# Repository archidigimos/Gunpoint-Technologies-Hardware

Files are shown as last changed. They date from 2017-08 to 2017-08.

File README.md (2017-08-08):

# Gunpoint-Technologies-Hardware
Lasertag gaming hardware. Product developed for gaming, entertainment and battlefield simulation purpose for military.
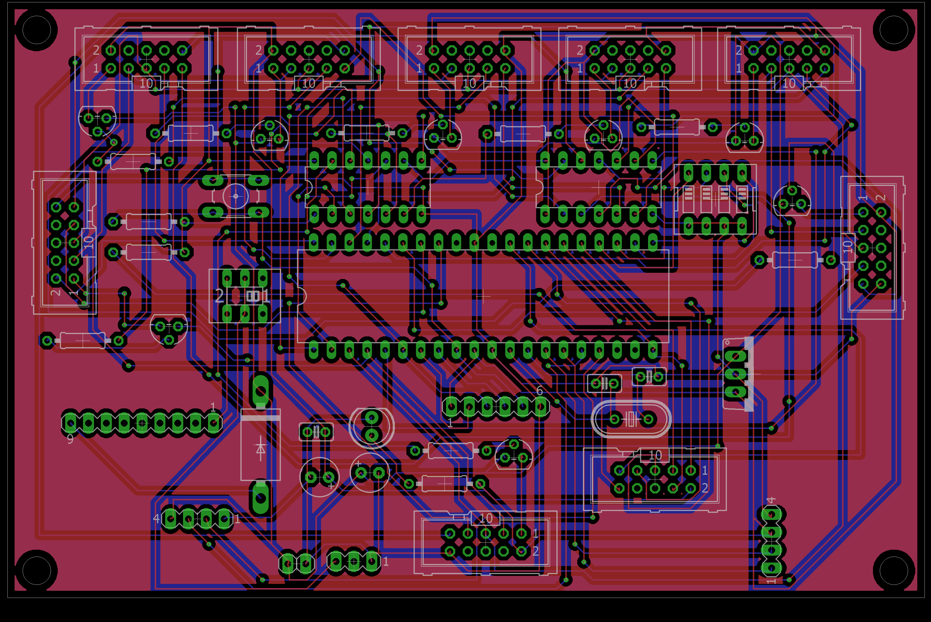
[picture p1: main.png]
Logic board to control sensor boards

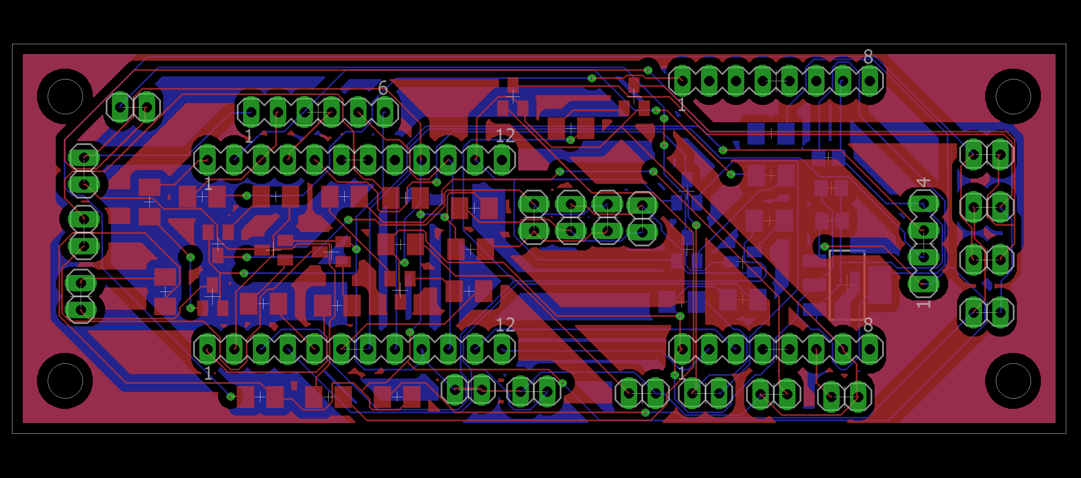
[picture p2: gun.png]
Gun logic board

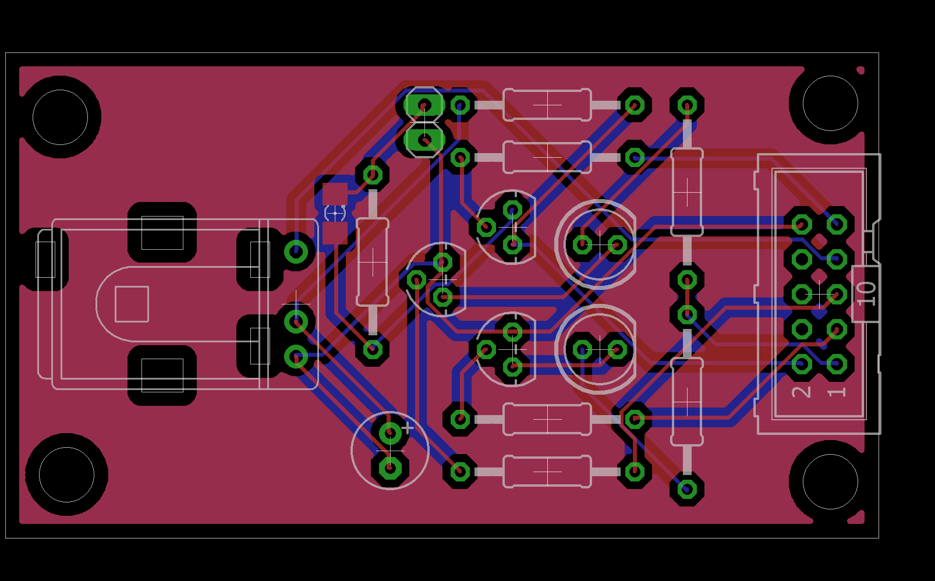
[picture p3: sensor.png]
Sensor board


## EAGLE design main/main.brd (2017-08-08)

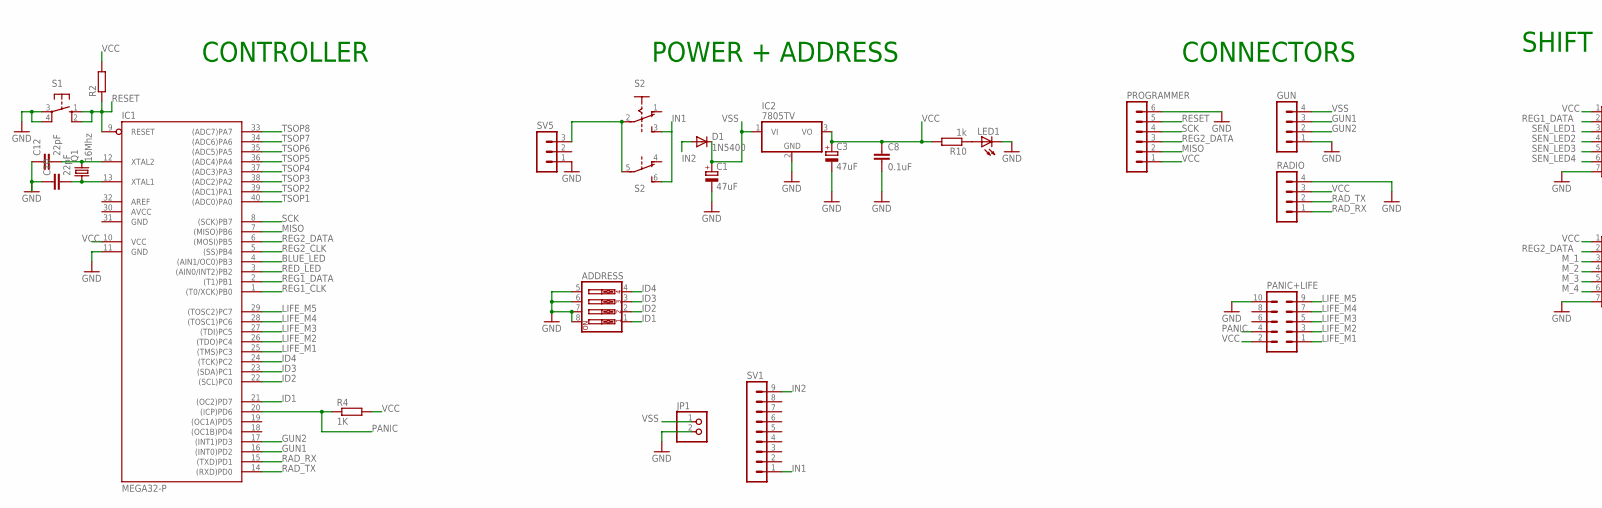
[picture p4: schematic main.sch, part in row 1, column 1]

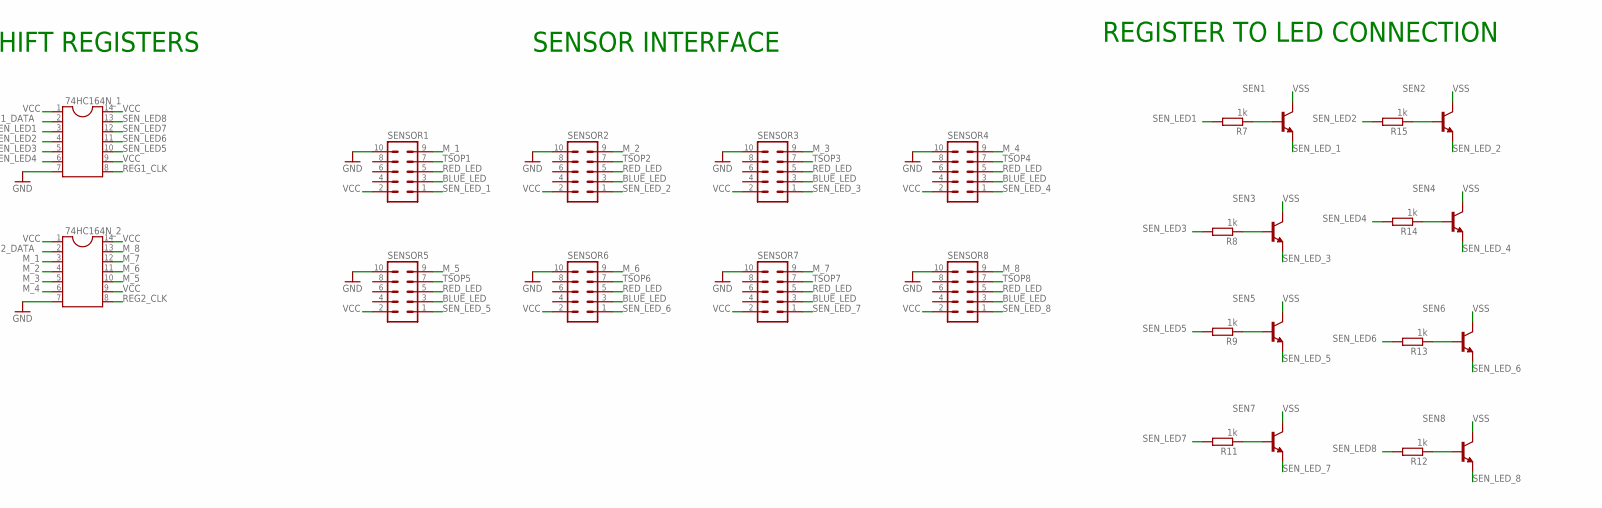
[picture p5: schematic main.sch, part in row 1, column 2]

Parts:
74HC164N_1, 74HC164N_2: DIL14
ADDRESS: SW_DIP-4; EDG-04
C1, C3: 47uF; E2,5-6
C8: 0.1uF; C025-025X050
C10, C12: 22pF; C025-025X050
D1: 1N5400; DO201-15
GUN: MA04-1
IC1: MEGA32-P; DIL40
IC2: 7805TV; TO220V
JP1: PINHD-1X2; 1X02
LED1: LED5MM
PANIC+LIFE: ML10
PROGRAMMER: MA06-1
Q1: 16Mhz; HC49U70
R2: R-EU_0207/10; 0207/10
R4: 1K; 0207/10
R7, R8, R9, R10, R11, R12, R13, R14, R15: 1k; 0207/10
RADIO: MA04-1
S1: 10-XX; B3F-10XX
S2: A68-A31
SEN1, SEN2, SEN3, SEN4, SEN5, SEN6, SEN7, SEN8: BC547; TO92
SENSOR1, SENSOR2, SENSOR3, SENSOR4, SENSOR5, SENSOR6, SENSOR7, SENSOR8: ML10
SV1: MA09-1
SV5: MA03-1

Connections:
AVCC: IC1.30 (AVCC)
BLUE_LED: IC1.4 ((AIN1/OC0)PB3), SENSOR1.3, SENSOR2.3, SENSOR3.3, SENSOR4.3, SENSOR5.3, SENSOR6.3, SENSOR7.3, SENSOR8.3
GND: 74HC164N_1.7, 74HC164N_2.7, ADDRESS.5, ADDRESS.6, ADDRESS.7, ADDRESS.8, C1.-, C3.-, C8.2, C10.1, C12.1, GUN.1, IC1.11 (GND), IC1.31 (GND), IC2.2 (GND), JP1.2, LED1.K (C), PANIC+LIFE.10, PROGRAMMER.6, RADIO.4, S1.3, S1.4 (P1), SENSOR1.10, SENSOR2.10, SENSOR3.10, SENSOR4.10, SENSOR5.10, SENSOR6.10, SENSOR7.10, SENSOR8.10, SV5.1
GUN1: GUN.3, IC1.16 ((INT0)PD2)
GUN2: GUN.2, IC1.17 ((INT1)PD3)
ID1: ADDRESS.1, IC1.21 ((OC2)PD7)
ID2: ADDRESS.2, IC1.22 ((SCL)PC0)
ID3: ADDRESS.3, IC1.23 ((SDA)PC1)
ID4: ADDRESS.4, IC1.24 ((TCK)PC2)
IN1: S2.3 (S), S2.6 (S), SV1.1
IN2: D1.A, SV1.9
LIFE_M1: IC1.25 ((TMS)PC3), PANIC+LIFE.1
LIFE_M2: IC1.26 ((TDO)PC4), PANIC+LIFE.3
LIFE_M3: IC1.27 ((TDI)PC5), PANIC+LIFE.5
LIFE_M4: IC1.28 ((TOSC1)PC6), PANIC+LIFE.7
LIFE_M5: IC1.29 ((TOSC2)PC7), PANIC+LIFE.9
MISO: IC1.7 ((MISO)PB6), PROGRAMMER.2
M_1: 74HC164N_2.3, SENSOR1.9
M_2: 74HC164N_2.4, SENSOR2.9
M_3: 74HC164N_2.5, SENSOR3.9
M_4: 74HC164N_2.6, SENSOR4.9
M_5: 74HC164N_2.10, SENSOR5.9
M_6: 74HC164N_2.11, SENSOR6.9
M_7: 74HC164N_2.12, SENSOR7.9
M_8: 74HC164N_2.13, SENSOR8.9
unnamed: C12.2, IC1.12 (XTAL2), Q1.2
unnamed: C10.2, IC1.13 (XTAL1), Q1.1
unnamed: LED1.A, R10.1
unnamed: R7.1, SEN1.2 (B)
unnamed: R15.1, SEN2.2 (B)
unnamed: S2.2, S2.5, SV5.3
unnamed: R8.1, SEN3.2 (B)
unnamed: R14.1, SEN4.2 (B)
unnamed: R9.1, SEN5.2 (B)
unnamed: R13.1, SEN6.2 (B)
unnamed: R11.1, SEN7.2 (B)
unnamed: R12.1, SEN8.2 (B)
PANIC: IC1.20 ((ICP)PD6), PANIC+LIFE.4, R4.1
RAD_RX: IC1.15 ((TXD)PD1), RADIO.1
RAD_TX: IC1.14 ((RXD)PD0), RADIO.2
RED_LED: IC1.3 ((AIN0/INT2)PB2), SENSOR1.5, SENSOR2.5, SENSOR3.5, SENSOR4.5, SENSOR5.5, SENSOR6.5, SENSOR7.5, SENSOR8.5
REG1_CLK: 74HC164N_1.8, IC1.1 ((T0/XCK)PB0)
REG1_DATA: 74HC164N_1.2, IC1.2 ((T1)PB1)
REG2_CLK: 74HC164N_2.8, IC1.5 ((SS)PB4)
REG2_DATA: 74HC164N_2.2, IC1.6 ((MOSI)PB5), PROGRAMMER.3
RESET: IC1.9 (RESET), PROGRAMMER.5, R2.1, S1.1 (S), S1.2 (S1)
SCK: IC1.8 ((SCK)PB7), PROGRAMMER.4
SEN_LED1: 74HC164N_1.3, R7.2
SEN_LED2: 74HC164N_1.4, R15.2
SEN_LED3: 74HC164N_1.5, R8.2
SEN_LED4: 74HC164N_1.6, R14.2
SEN_LED5: 74HC164N_1.10, R9.2
SEN_LED6: 74HC164N_1.11, R13.2
SEN_LED7: 74HC164N_1.12, R11.2
SEN_LED8: 74HC164N_1.13, R12.2
SEN_LED_1: SEN1.1 (E), SENSOR1.1
SEN_LED_2: SEN2.1 (E), SENSOR2.1
SEN_LED_3: SEN3.1 (E), SENSOR3.1
SEN_LED_4: SEN4.1 (E), SENSOR4.1
SEN_LED_5: SEN5.1 (E), SENSOR5.1
SEN_LED_6: SEN6.1 (E), SENSOR6.1
SEN_LED_7: SEN7.1 (E), SENSOR7.1
SEN_LED_8: SEN8.1 (E), SENSOR8.1
TSOP1: IC1.40 ((ADC0)PA0), SENSOR1.7
TSOP2: IC1.39 ((ADC1)PA1), SENSOR2.7
TSOP3: IC1.38 ((ADC2)PA2), SENSOR3.7
TSOP4: IC1.37 ((ADC3)PA3), SENSOR4.7
TSOP5: IC1.36 ((ADC4)PA4), SENSOR5.7
TSOP6: IC1.35 ((ADC5)PA5), SENSOR6.7
TSOP7: IC1.34 ((ADC6)PA6), SENSOR7.7
TSOP8: IC1.33 ((ADC7)PA7), SENSOR8.7
VCC: 74HC164N_1.1, 74HC164N_1.9, 74HC164N_1.14, 74HC164N_2.1, 74HC164N_2.9, 74HC164N_2.14, C3.+, C8.1, IC1.10 (VCC), IC2.3 (VO), PANIC+LIFE.2, PROGRAMMER.1, R2.2, R4.2, R10.2, RADIO.3, SENSOR1.2, SENSOR2.2, SENSOR3.2, SENSOR4.2, SENSOR5.2, SENSOR6.2, SENSOR7.2, SENSOR8.2
VSS: C1.+, D1.C, GUN.4, IC2.1 (VI), JP1.1, SEN1.3 (C), SEN2.3 (C), SEN3.3 (C), SEN4.3 (C), SEN5.3 (C), SEN6.3 (C), SEN7.3 (C), SEN8.3 (C)

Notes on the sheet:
CONTROLLER
POWER + ADDRESS
CONNECTORS
SHIFT REGISTERS
SENSOR INTERFACE
REGISTER TO LED CONNECTION

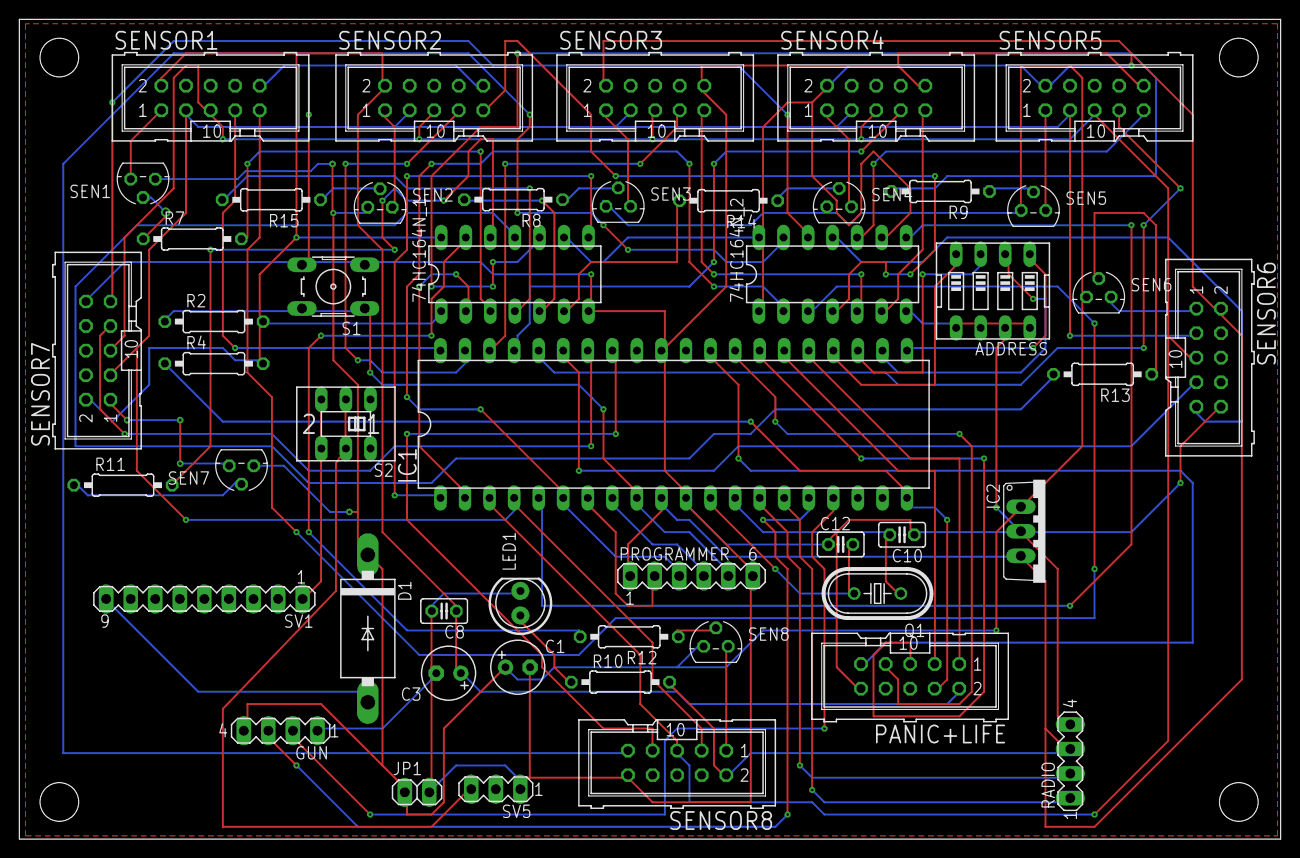
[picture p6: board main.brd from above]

Board: 2 copper layers, 130.5 x 84.8 mm, 49 parts (0 on the bottom side), 72 nets.

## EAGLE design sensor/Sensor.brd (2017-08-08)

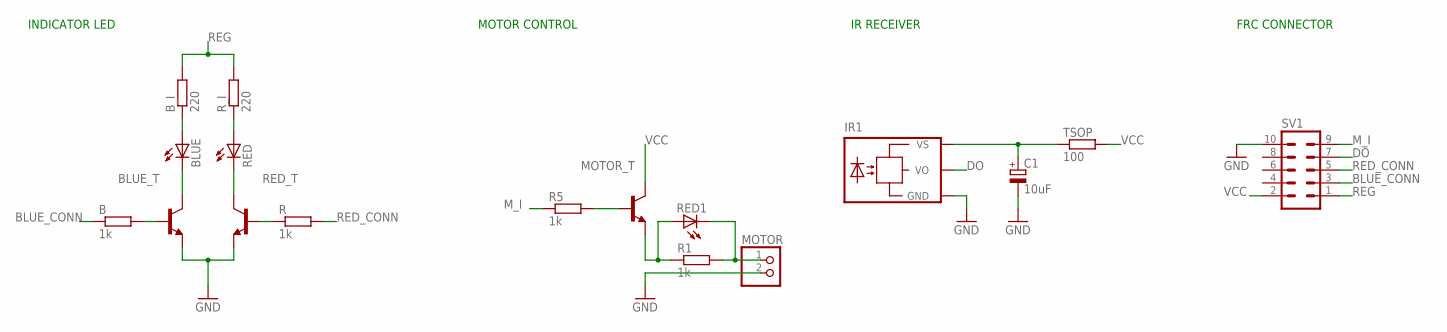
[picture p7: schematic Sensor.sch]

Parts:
B: 1k; 0207/12
BLUE: LED5MM
BLUE_T: BC547; TO92
B_I: 220; 0207/12
C1: 10uF; E2,5-6
IR1: TSOP1730TB1; TSOP17_TB1
MOTOR: PINHD-1X2; 1X02
MOTOR_T: BC547; TO92
R, R1, R5: 1k; 0207/12
RED: LED5MM
RED1: LEDSMT1206; 1206
RED_T: BC547; TO92
R_I: 220; 0207/12
SV1: ML10
TSOP: 100; 0207/12

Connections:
BLUE_CONN: B.1, SV1.3
DO: IR1.VO, SV1.7
GND: BLUE_T.1 (E), C1.-, IR1.GND, MOTOR.2, RED_T.1 (E), SV1.10
M_I: R5.1, SV1.9
unnamed: BLUE.A, B_I.1
unnamed: C1.+, IR1.VS, TSOP.1
unnamed: BLUE.K (C), BLUE_T.3 (C)
unnamed: RED.K (C), RED_T.3 (C)
unnamed: MOTOR_T.2 (B), R5.2
unnamed: MOTOR_T.1 (E), R1.1, RED1.A
unnamed: B.2, BLUE_T.2 (B)
unnamed: R.1, RED_T.2 (B)
unnamed: MOTOR.1, R1.2, RED1.C
RED_CONN: R.2, SV1.5
REG: B_I.2, R_I.2, SV1.1
R_I: RED.A, R_I.1
VCC: MOTOR_T.3 (C), SV1.2, TSOP.2

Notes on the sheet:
INDICATOR LED
MOTOR CONTROL
IR RECEIVER
FRC CONNECTOR

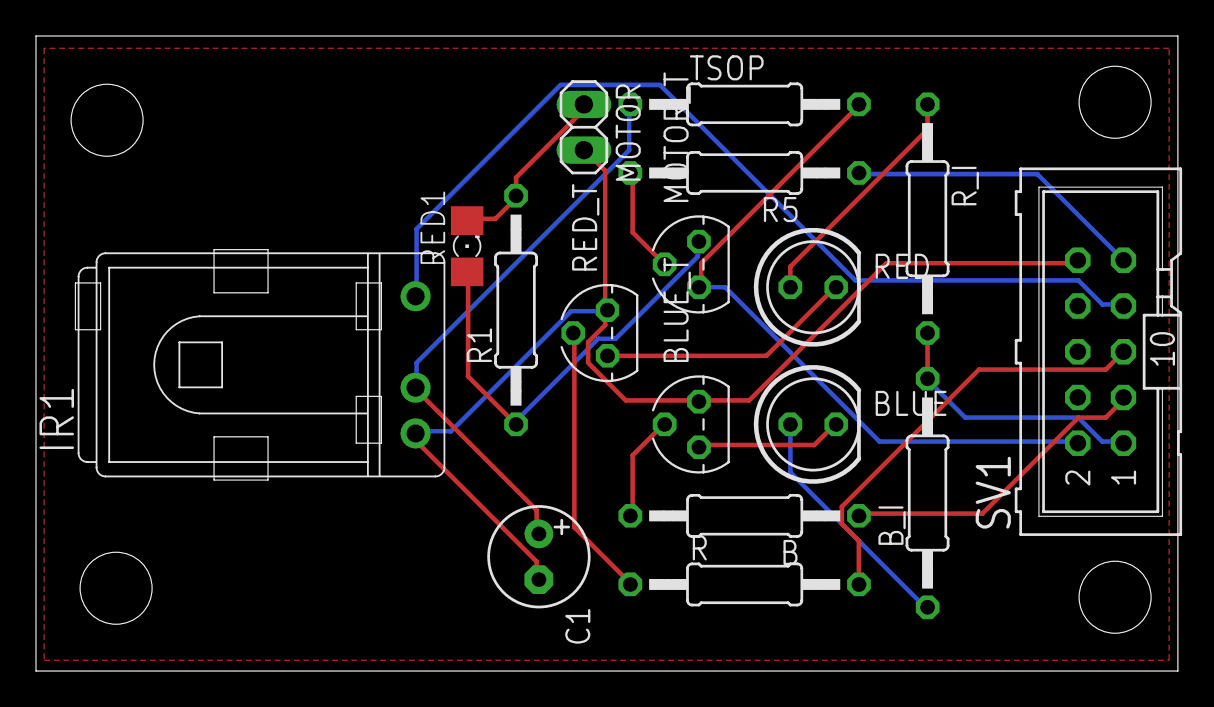
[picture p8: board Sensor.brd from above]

Board: 2 copper layers, 63.4 x 35.3 mm, 17 parts (0 on the bottom side), 17 nets.

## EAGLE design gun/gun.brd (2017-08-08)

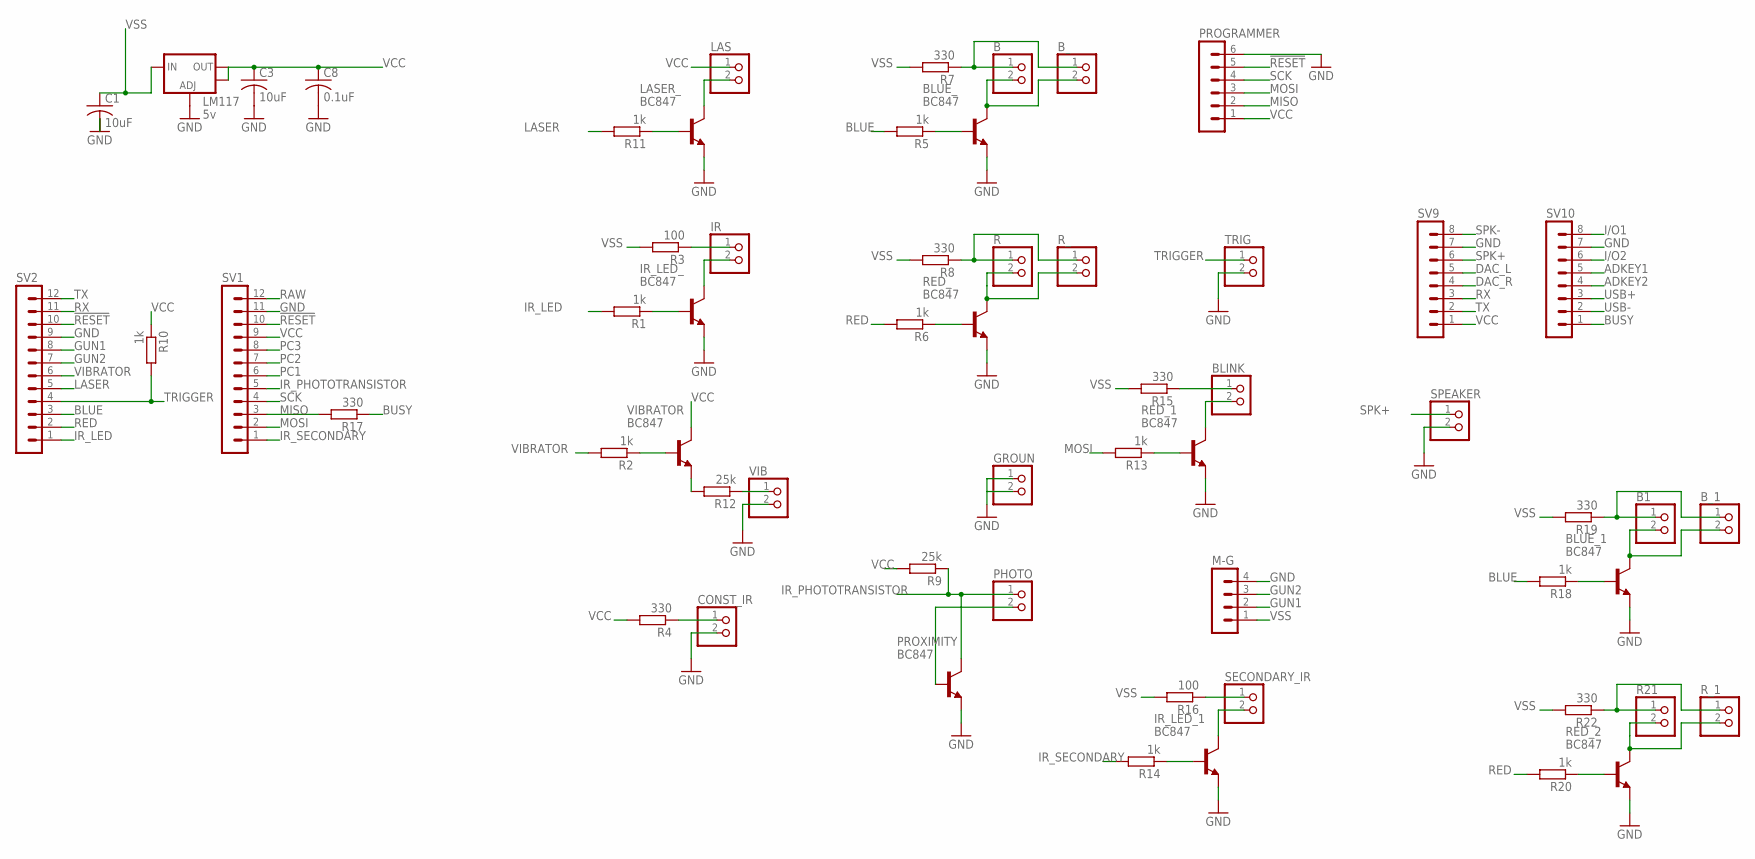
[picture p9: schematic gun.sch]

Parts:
B, B1: PINHD-1X2; 1X02
BLINK: PINHD-1X2; 1X02
BLUE_, BLUE_1: BC847; SOT23
B_, B_1: PINHD-1X2; 1X02
C1, C3: 10uF; C0805
C8: 0.1uF; C0805
CONST_IR: PINHD-1X2; 1X02
GROUN: PINHD-1X2; 1X02
IR: PINHD-1X2; 1X02
IR_LED_, IR_LED_1: BC847; SOT23
LAS: PINHD-1X2; 1X02
LASER_: BC847; SOT23
LM117: 5v; SOT223
M-G: MA04-1
PHOTO: PINHD-1X2; 1X02
PROGRAMMER: MA06-1
PROXIMITY: BC847; SOT23
R, R21: PINHD-1X2; 1X02
R1, R2, R5, R6, R10, R11, R13, R14, R18, R20: 1k; M1206
R3, R16: 100; M1206
R4, R7, R8, R15, R17, R19, R22: 330; M1206
R9, R12: 25k; M1206
RED_, RED_1, RED_2: BC847; SOT23
R_, R_1: PINHD-1X2; 1X02
SECONDARY_IR: PINHD-1X2; 1X02
SPEAKER: PINHD-1X2; 1X02
SV1, SV2: MA12-1
SV9, SV10: MA08-1
TRIG: PINHD-1X2; 1X02
VIB: PINHD-1X2; 1X02
VIBRATOR: BC847; SOT23

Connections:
!RESET: PROGRAMMER.5, SV1.10, SV2.10
ADKEY1: SV10.5
ADKEY2: SV10.4
BLUE: R5.2, R18.2, SV2.3
BUSY: R17.1, SV10.1
DAC_L: SV9.5
DAC_R: SV9.4
GND: BLUE_.2 (E), BLUE_1.2 (E), C1.2, C3.2, C8.2, CONST_IR.2, GROUN.1, GROUN.2, IR_LED_.2 (E), IR_LED_1.2 (E), LASER_.2 (E), LM117.1 (ADJ), M-G.4, PROGRAMMER.6, PROXIMITY.2 (E), RED_.2 (E), RED_1.2 (E), RED_2.2 (E), SPEAKER.2, SV1.11, SV2.9, SV9.7, SV10.7, TRIG.2, VIB.2
GUN1: M-G.2, SV2.8
GUN2: M-G.3, SV2.7
I/O1: SV10.8
I/O2: SV10.6
IR_LED: R1.2, SV2.1
IR_PHOTOTRANSISTOR: PHOTO.1, PROXIMITY.3 (C), R9.1, SV1.5
IR_SECONDARY: R14.2, SV1.1
LASER: R11.2, SV2.5
MISO: PROGRAMMER.2, R17.2, SV1.3
MOSI: PROGRAMMER.3, R13.2, SV1.2
unnamed: PHOTO.2, PROXIMITY.1 (B)
unnamed: R12.1, VIB.1
unnamed: IR_LED_.1 (B), R1.1
unnamed: R2.1, VIBRATOR.1 (B)
unnamed: R12.2, VIBRATOR.2 (E)
unnamed: IR.1, R3.1
unnamed: IR.2, IR_LED_.3 (C)
unnamed: CONST_IR.1, R4.1
unnamed: LAS.2, LASER_.3 (C)
unnamed: R13.1, RED_1.1 (B)
unnamed: BLUE_.1 (B), R5.1
unnamed: B.2, BLUE_.3 (C), B_.2
unnamed: R6.1, RED_.1 (B)
unnamed: R.2, RED_.3 (C), R_.2
unnamed: B.1, B_.1, R7.1
unnamed: R.1, R8.1, R_.1
unnamed: BLINK.2, RED_1.3 (C)
unnamed: BLINK.1, R15.1
unnamed: LASER_.1 (B), R11.1
unnamed: IR_LED_1.1 (B), R14.1
unnamed: IR_LED_1.3 (C), SECONDARY_IR.2
unnamed: R16.1, SECONDARY_IR.1
unnamed: BLUE_1.1 (B), R18.1
unnamed: B1.2, BLUE_1.3 (C), B_1.2
unnamed: B1.1, B_1.1, R19.1
unnamed: R20.1, RED_2.1 (B)
unnamed: R21.2, RED_2.3 (C), R_1.2
unnamed: R21.1, R22.1, R_1.1
PC1: SV1.6
PC2: SV1.7
PC3: SV1.8
RAW: SV1.12
RED: R6.2, R20.2, SV2.2
RX: SV2.11, SV9.3
SCK: PROGRAMMER.4, SV1.4
SPK+: SPEAKER.1, SV9.6
SPK-: SV9.8
TRIGGER: R10.2, SV2.4, TRIG.1
TX: SV2.12, SV9.2
USB+: SV10.3
USB-: SV10.2
VCC: C3.1, C8.1, LAS.1, LM117.2 (OUT), LM117.4 (OUT), PROGRAMMER.1, R4.2, R9.2, R10.1, SV1.9, SV9.1, VIBRATOR.3 (C)
VIBRATOR: R2.2, SV2.6
VSS: C1.1, LM117.3 (IN), M-G.1, R3.2, R7.2, R8.2, R15.2, R16.2, R19.2, R22.2

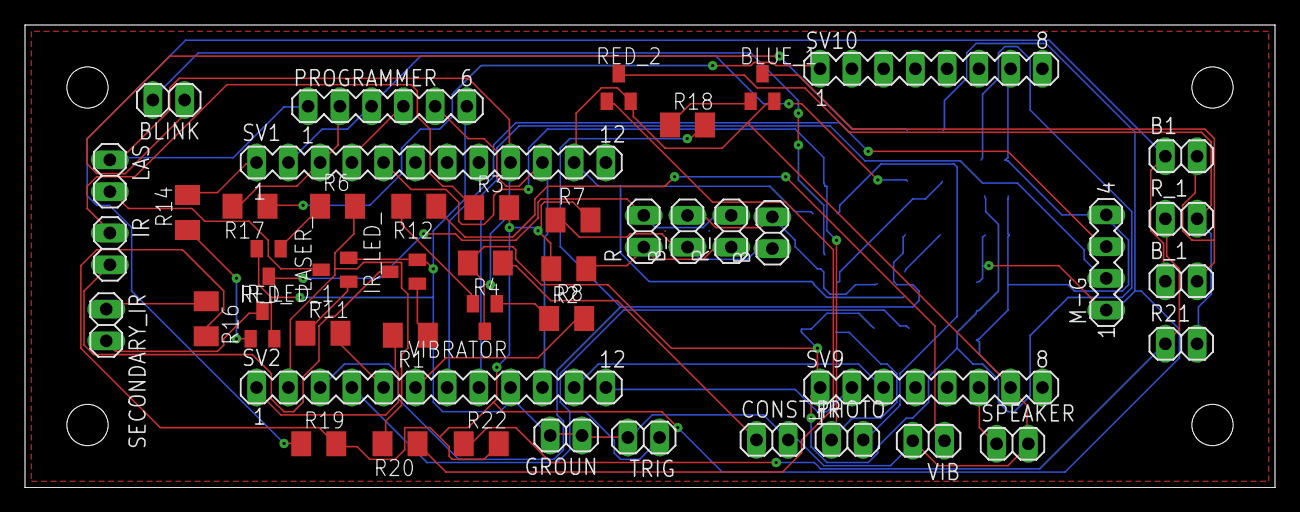
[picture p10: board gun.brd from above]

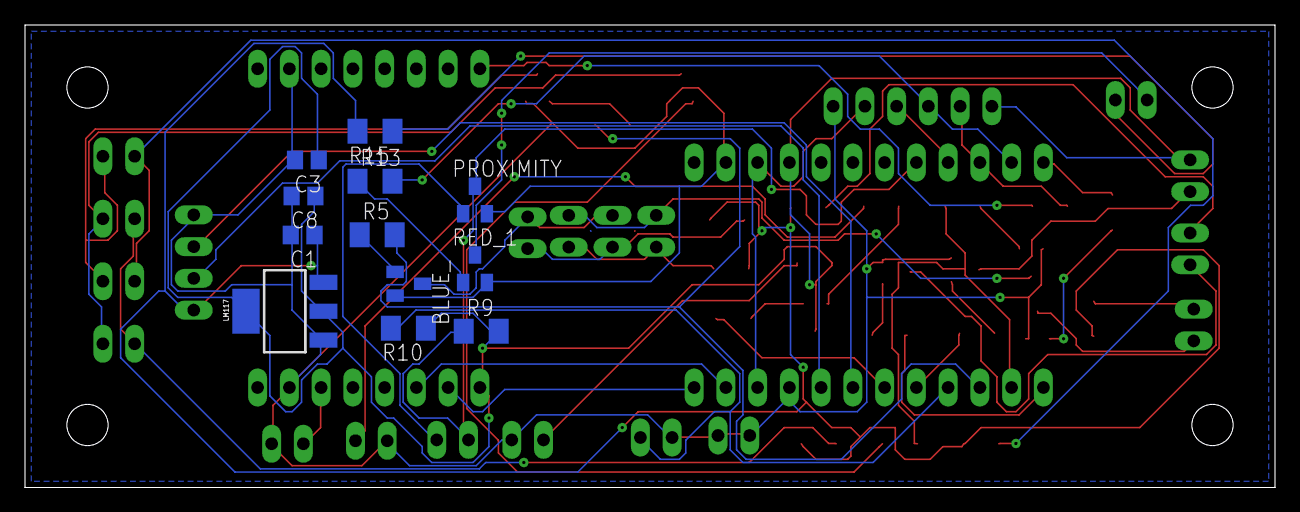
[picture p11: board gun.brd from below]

Board: 2 copper layers, 100.0 x 37.0 mm, 59 parts (12 on the bottom side), 49 nets.
